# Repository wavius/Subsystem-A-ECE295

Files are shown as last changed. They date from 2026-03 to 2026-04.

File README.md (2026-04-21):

# Subsystem A
## Overview
My team was tasked with implementing Subsystem A as part of the ECE295 hardware design course. This subsystem consists of an RX Filter and Quadrature Mixer and is part of the receive chain of the Flexible Radio Transceiver (FLRTRX).

<div align="left">
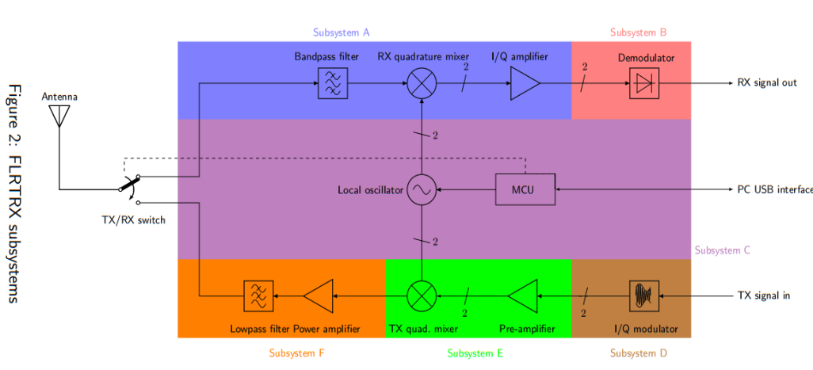
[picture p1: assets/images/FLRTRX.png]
  
</div>
<br>

## Motivation

The LNA and mixer are discrete implementations using NPN BJTs because I thought it was more fun and interesting to do it this way. I am pleased with the results and I have become much more comfortable designing and working with transistors.

I was previously quick to rush to the PCB design stage, but now have a lot more appreciation for simulation using spice. I think it is much more important (maybe obviously) to get the functionality right before arranging and routing components, even if the second part can seem more fun and less frustrating.

I had a wonderful experience with the design aspect of the course and would highly recommend others to take a similar discrete design approach.

## Design

<div align="left">
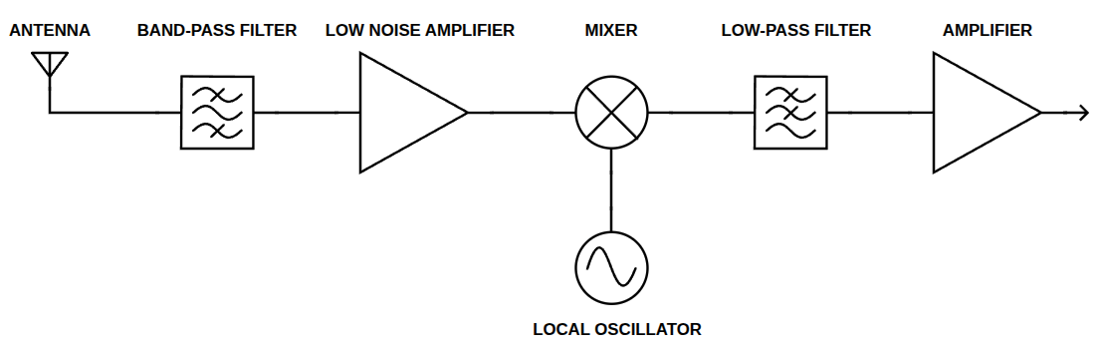
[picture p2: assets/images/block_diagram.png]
  
</div>
<br>

The design consists of five main stages that are described below in more detail.

[📄 View Schematic (PDF)](assets/pdf/Schematic.pdf)

### Band-pass Filter
* **Requirements**: 8 and 16 MHz cutoff frequencies; amplitude balance within 1dB.
* **Implementation**: 3rd-order passive Butterworth filter. 
* **Rationale**: A Butterworth response was chosen for its maximally flat passband to maintain amplitude balance across the 8-16 MHz window. A passive topology was used as the MHz-range bandwidth made active op-amp designs unfeasible.

### Low Noise Amplifier (LNA)
* **Requirements**: 50 $\Omega$ input impedance; Noise $< 3\text{nV}/\sqrt{\text{Hz}}$.
* **Implementation**: Cascode (common-emitter to common-base) amplifier.
* **Rationale**: Designed to compensate for band-pass filter insertion loss, mask noise contributions from subsequent stages, and present a 50 $\Omega$ match to the BPF to preserve the receiver signal integrity.

### Gilbert Cell Mixer
* **Requirements**: 90° (12.5° tolerance) phase difference between I/Q signals.
* **Implementation**: Active Gilbert Cell mixer.
* **Rationale**: An active topology avoids passive losses and provides superior local-oscillator-to-intermediate-frequency isolation for a cleaner output. 

### Low-pass Filter
* **Requirements**: 92 kHz cutoff frequency.
* **Implementation**: Second-order Sallen-Key active filter.
* **Rationale**: Yields a Butterworth response similar to the BPF but without passive insertion losses.

### Amplifier
* **Requirements**: $\ge 30\text{ dB}$ post-mixer gain.
* **Implementation**: Non-inverting amplifier.
* **Rationale**: Provides a dedicated stage for final gain control by swapping a single resistor while keeping previous stages isolated.

## PCB Assembly & Rework
The design was assembled using SMD components.

<div align="left">
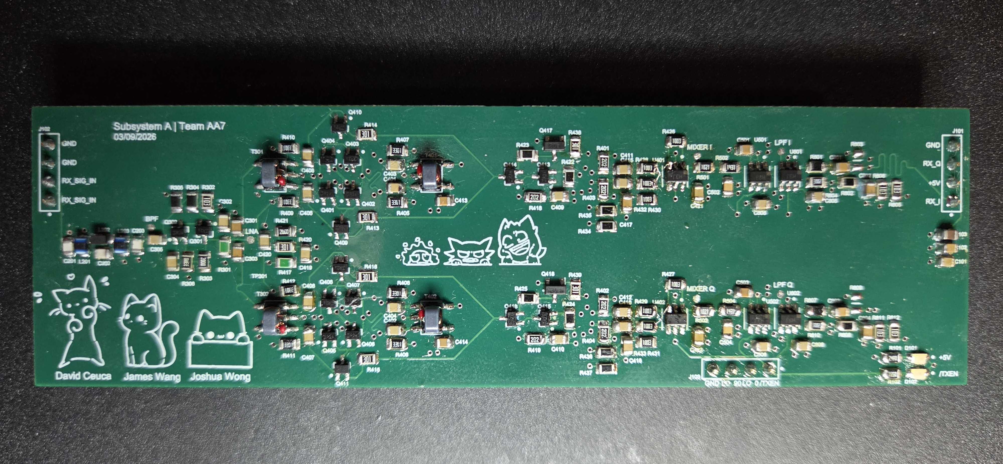
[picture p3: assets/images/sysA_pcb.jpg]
  
</div>
<br>

### Hardware Issues
During testing, it was discovered that the differential amplifier inverting and non-inverting pins were flipped during schematic capture and that this mistake made it into the final PCB. 

*Note: this issue has already been fixed in design files in this repository.*

* **Fix**: The affected op-amp pins were lifted to prevent pad contact and fine strands from a 22AWG wire were used to manually jump the pins to the correct resistor nodes.

<br>
<div align="left">
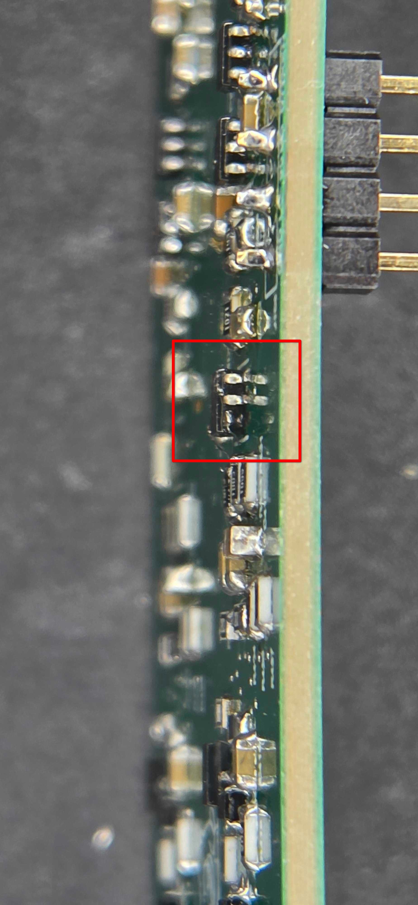
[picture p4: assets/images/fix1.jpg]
Fix 1
  
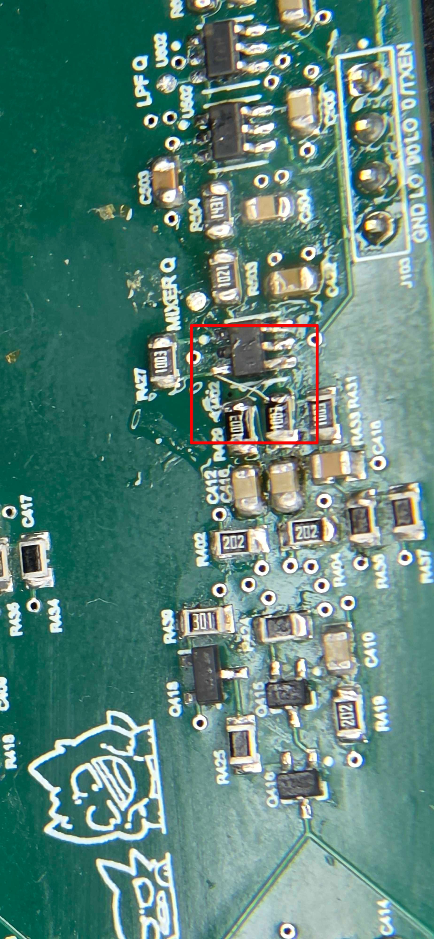
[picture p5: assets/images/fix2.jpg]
Fix 2
  
</div>
<br>

## Testing & Results

To verify the design, a $12.05\text{ MHz}$ RF signal was mixed with $12\text{ MHz}$ LO signals. The output signals were measured to be the correct $50\text{ kHz}$ intermediate frequency (IF), with the I and Q channels $90^\circ$ out of phase.

<div align="left">
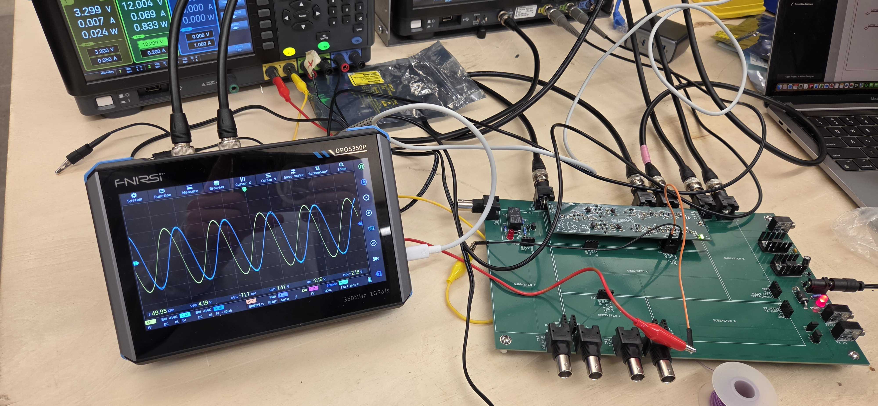
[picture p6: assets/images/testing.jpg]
  
</div>
<br>

Automated Python scripts were used to produce Bode plots for each stage.

| Band-pass Filter | Amplitude Balance |
| :---: | :---: |
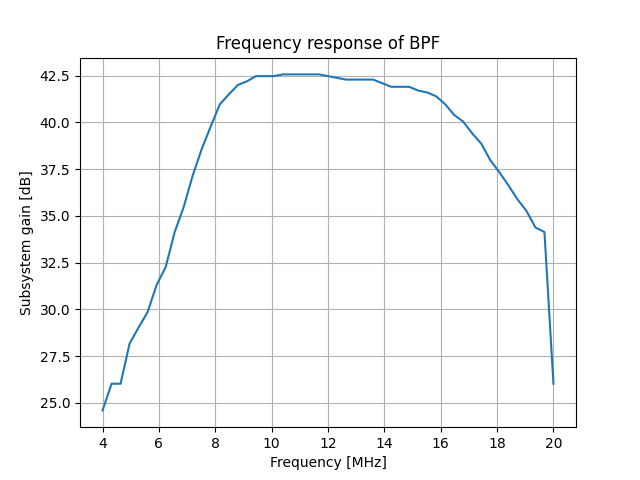
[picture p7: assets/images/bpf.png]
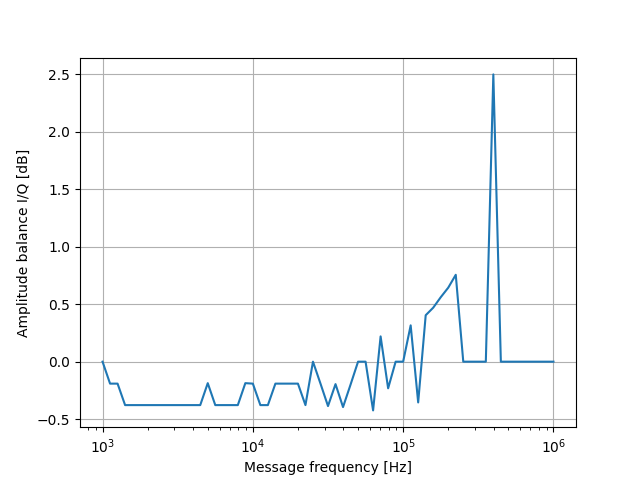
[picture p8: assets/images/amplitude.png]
|  |  |
| *Frequency response across the target passband* | *Balance difference between I/Q signals* |

| Low-pass Filter | I/Q Phase Difference |
| :---: | :---: |
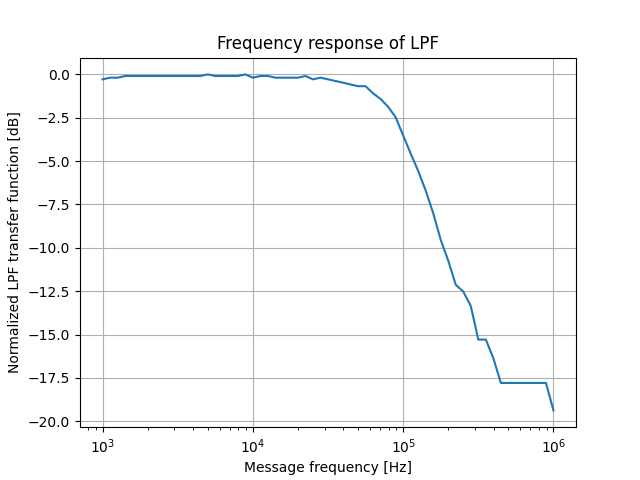
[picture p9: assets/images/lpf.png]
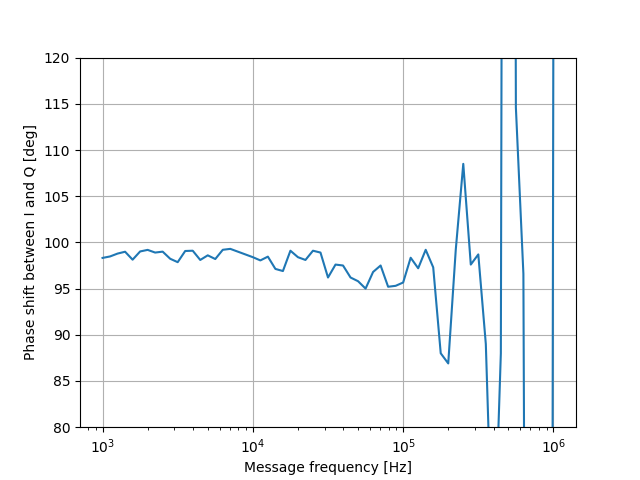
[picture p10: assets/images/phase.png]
|  |  |
| *92 kHz cutoff frequency response* | *90° quadrature separation verification* |

| Total Subsystem Gain |
| :---: |
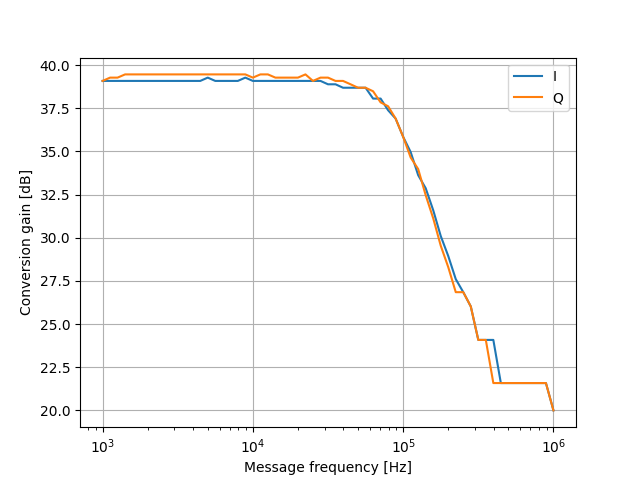
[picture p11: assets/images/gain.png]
|  |
| *Total signal gain throughout all stages* |

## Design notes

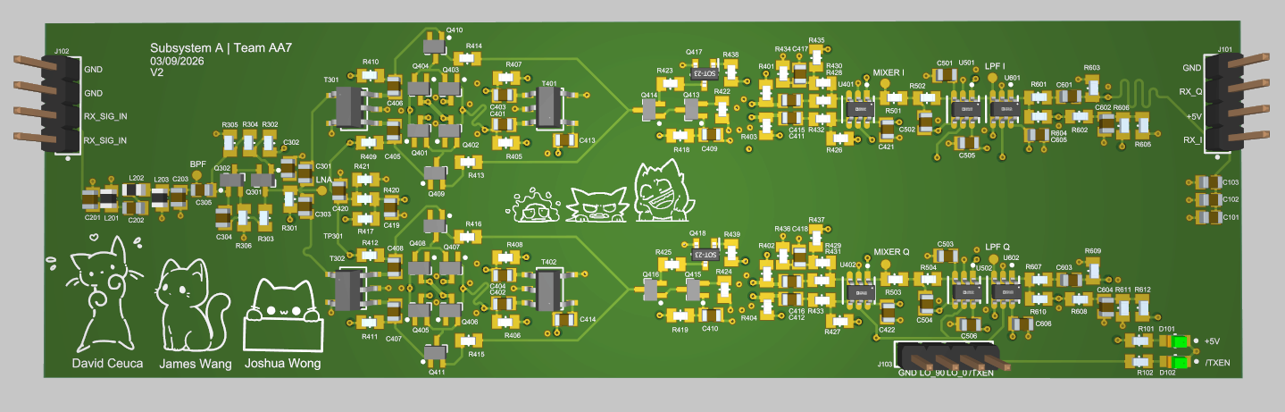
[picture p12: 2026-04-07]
assets/images/PCB_3D.png

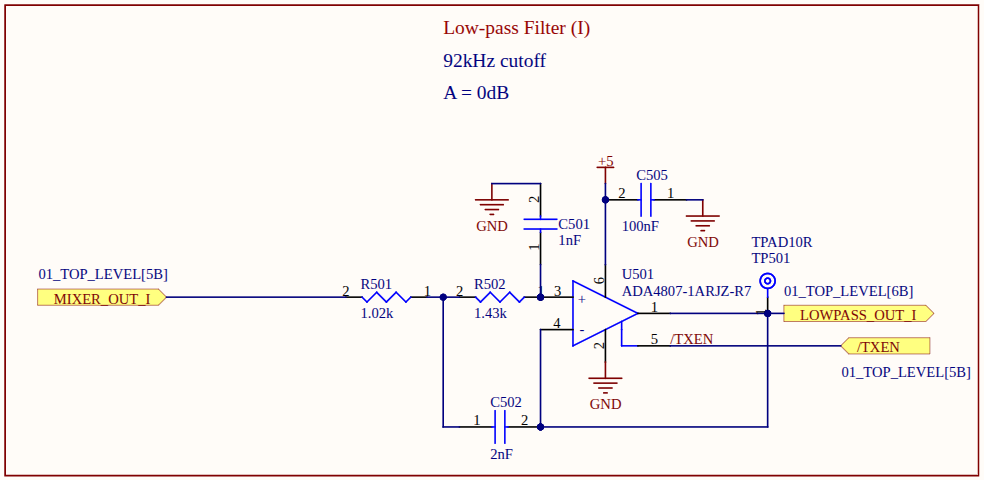
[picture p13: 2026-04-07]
assets/images/lpf_sch.png

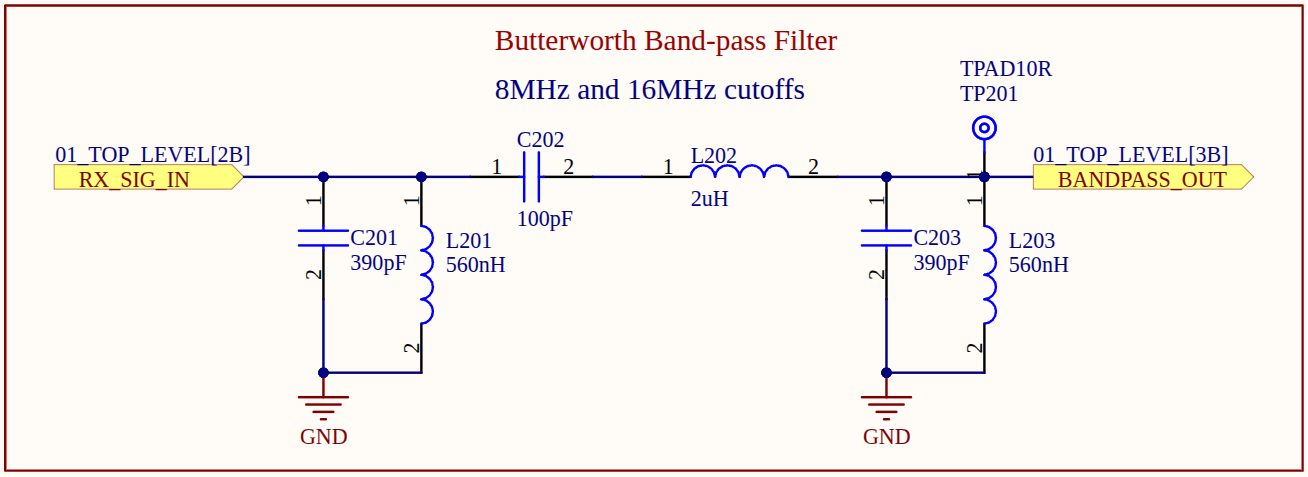
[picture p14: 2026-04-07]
assets/images/bpf_sch.png

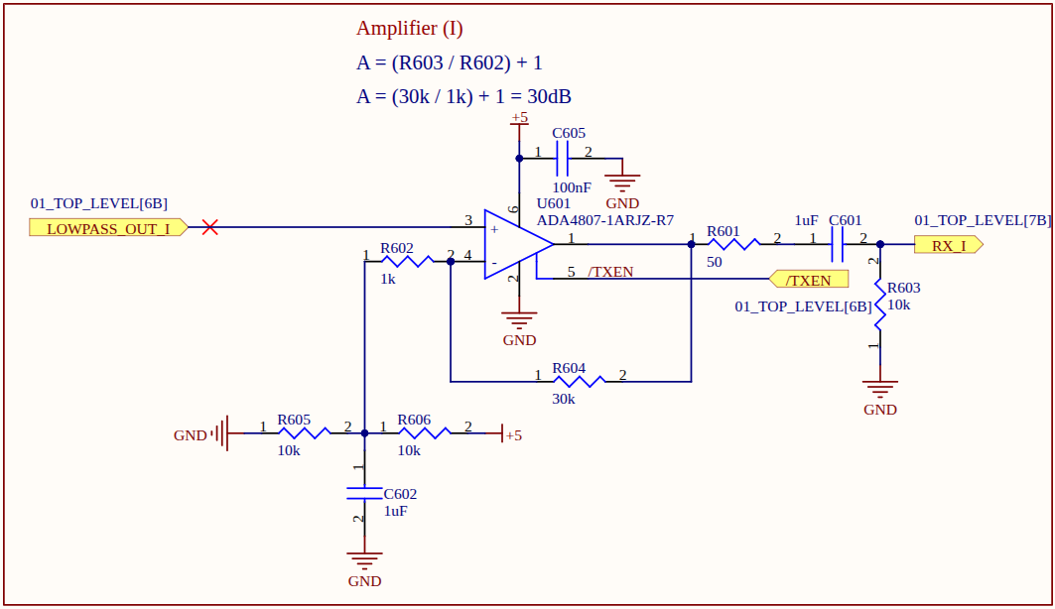
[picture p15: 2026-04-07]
assets/images/amplifier_sch.png

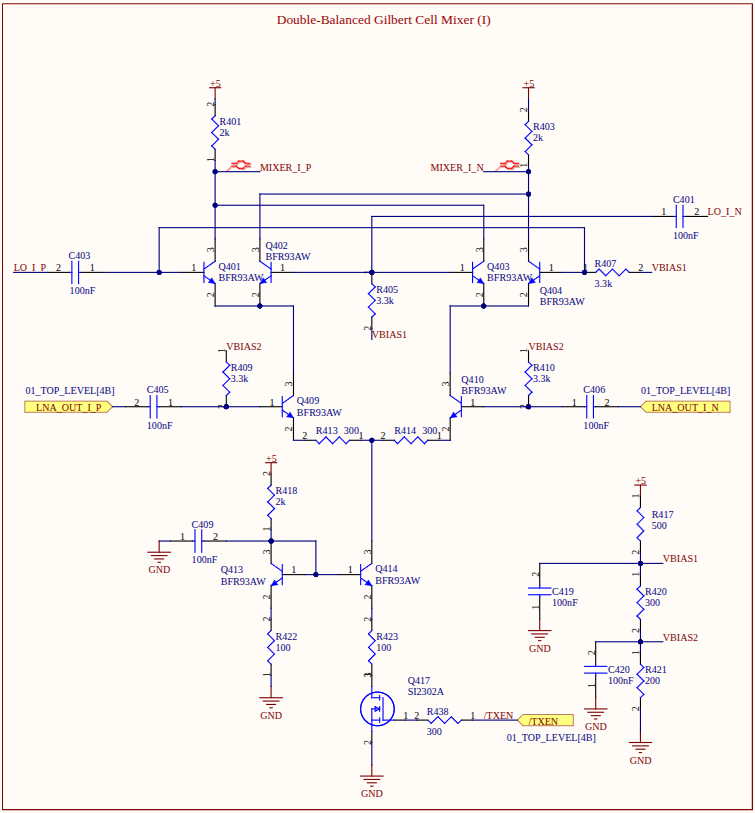
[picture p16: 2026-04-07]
assets/images/mixer_sch.png

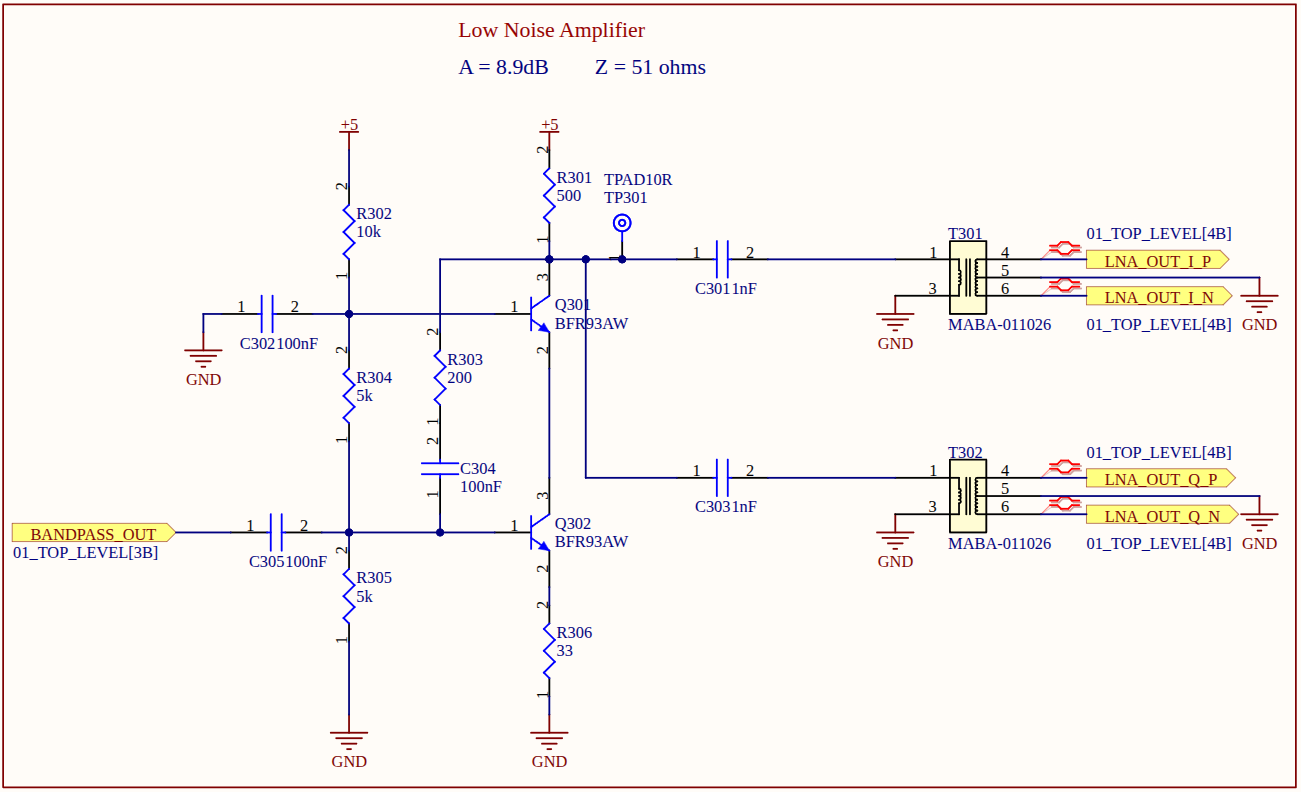
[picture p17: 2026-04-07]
assets/images/lna_sch.png

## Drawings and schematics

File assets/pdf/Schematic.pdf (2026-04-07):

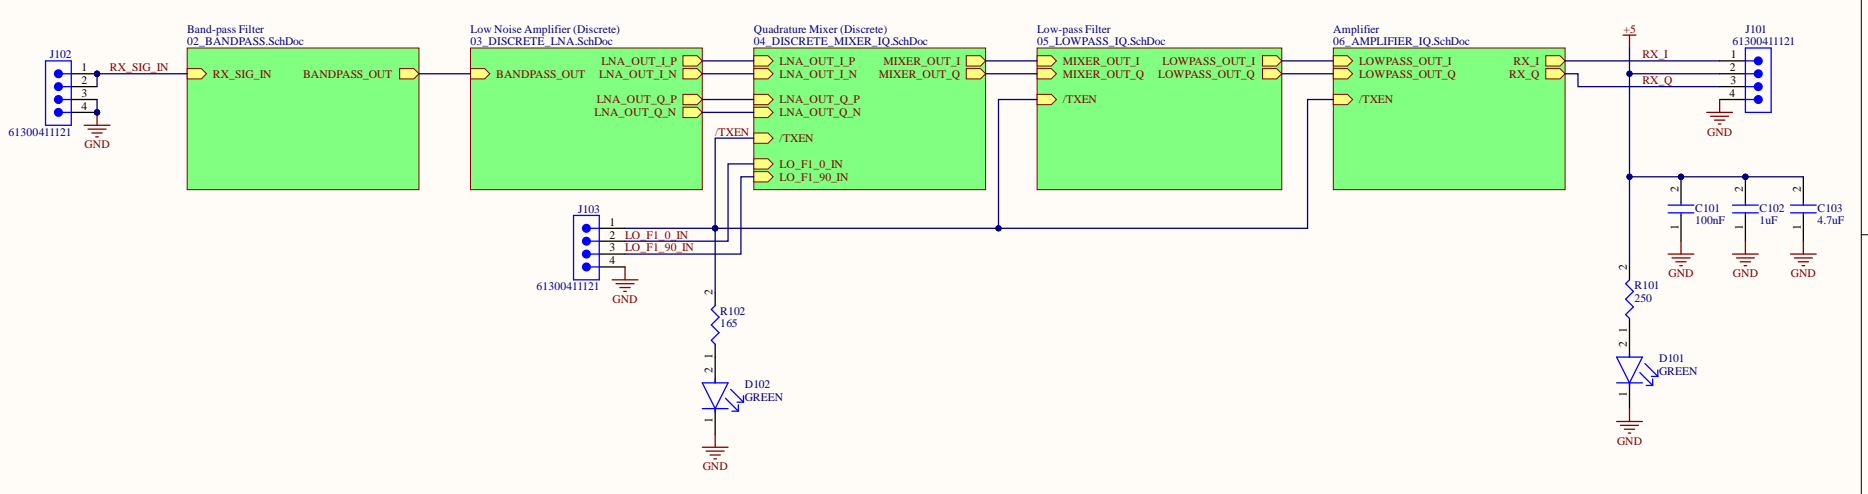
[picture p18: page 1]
ifier (D; ure Mi; xer (D

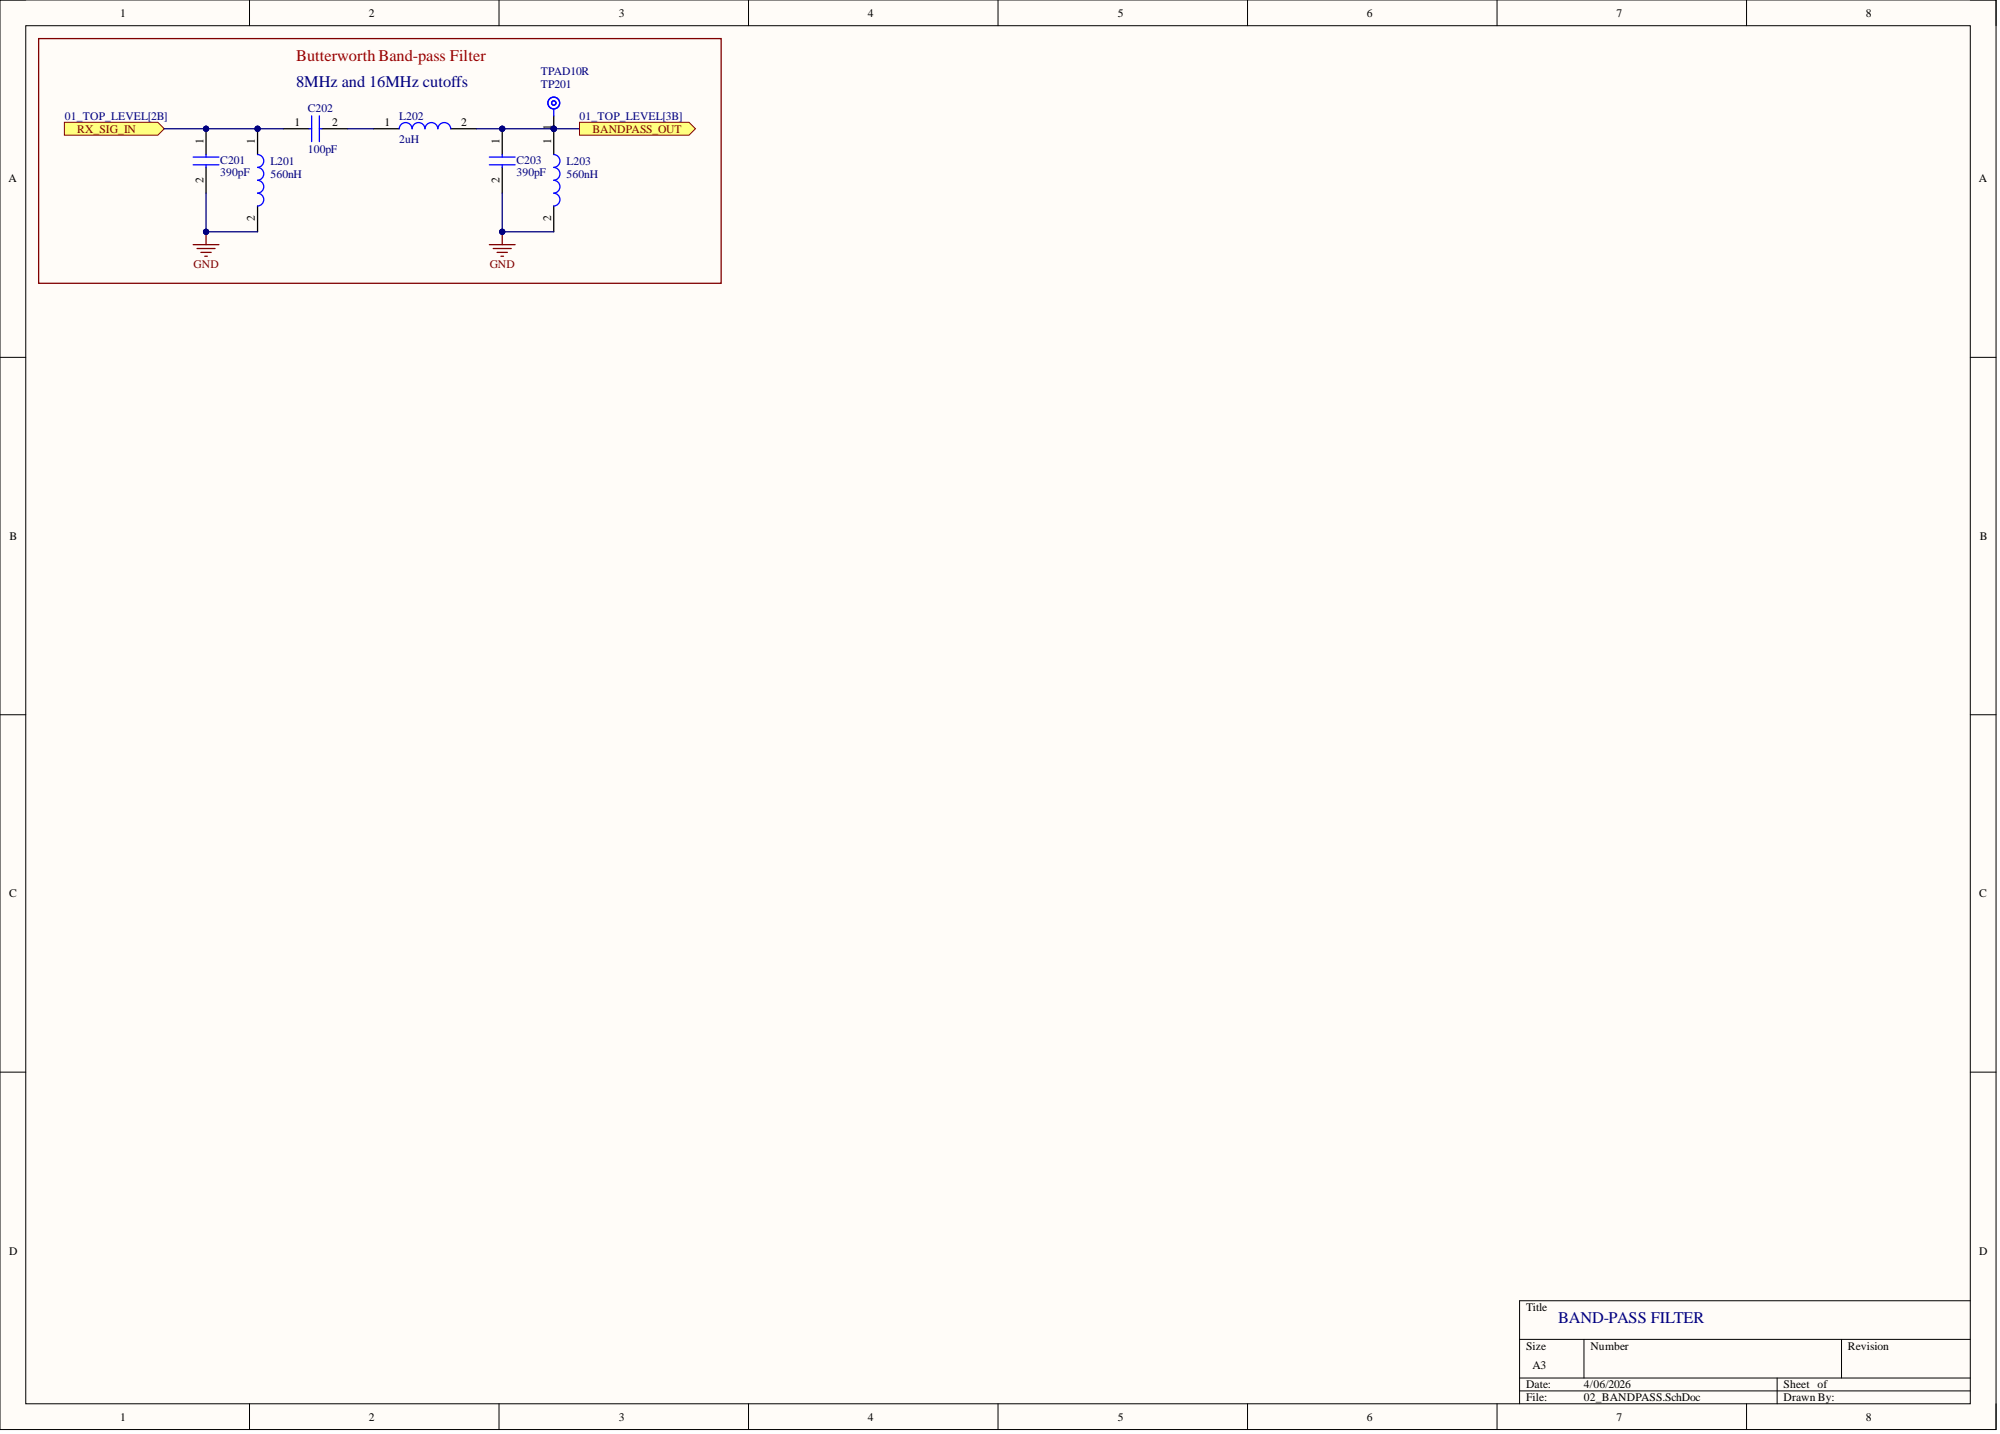
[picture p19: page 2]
Date:; Sheet of; File:; 02_BANDPASS.SchDoc; Drawn By:

Butterworth Band-pass Filter
8MHz and 16MHz cutoffs

Title
BAND-PASS FILTER

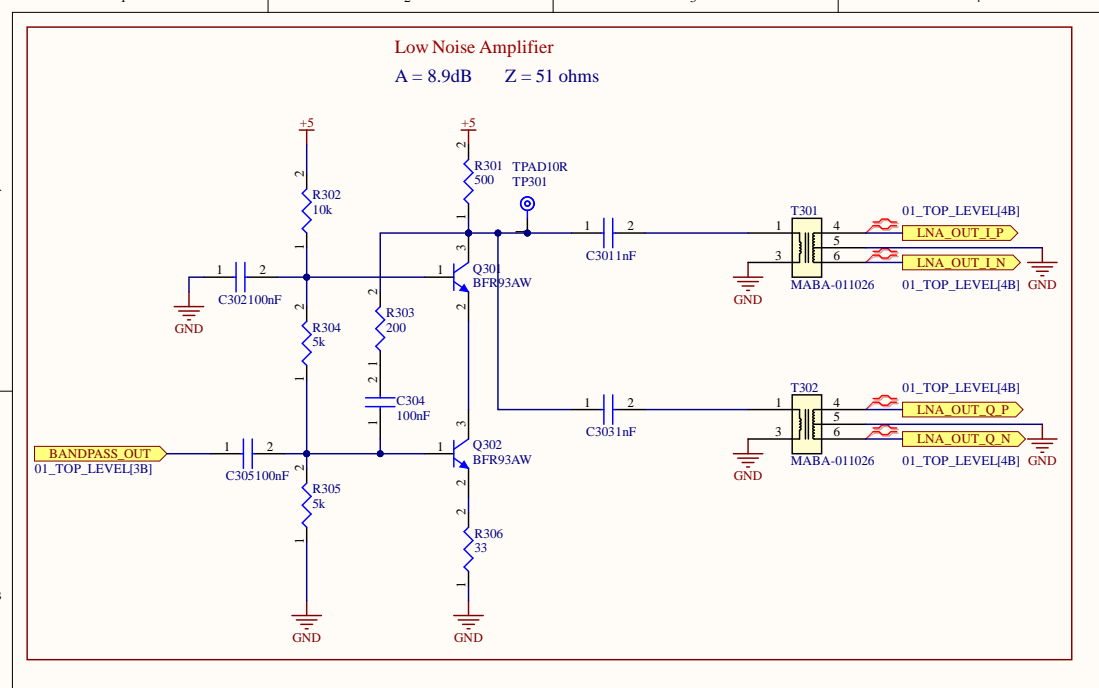
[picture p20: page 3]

Low Noise A = 8.9dB 0 2 | A mpl ifier Z = 51 ohm s

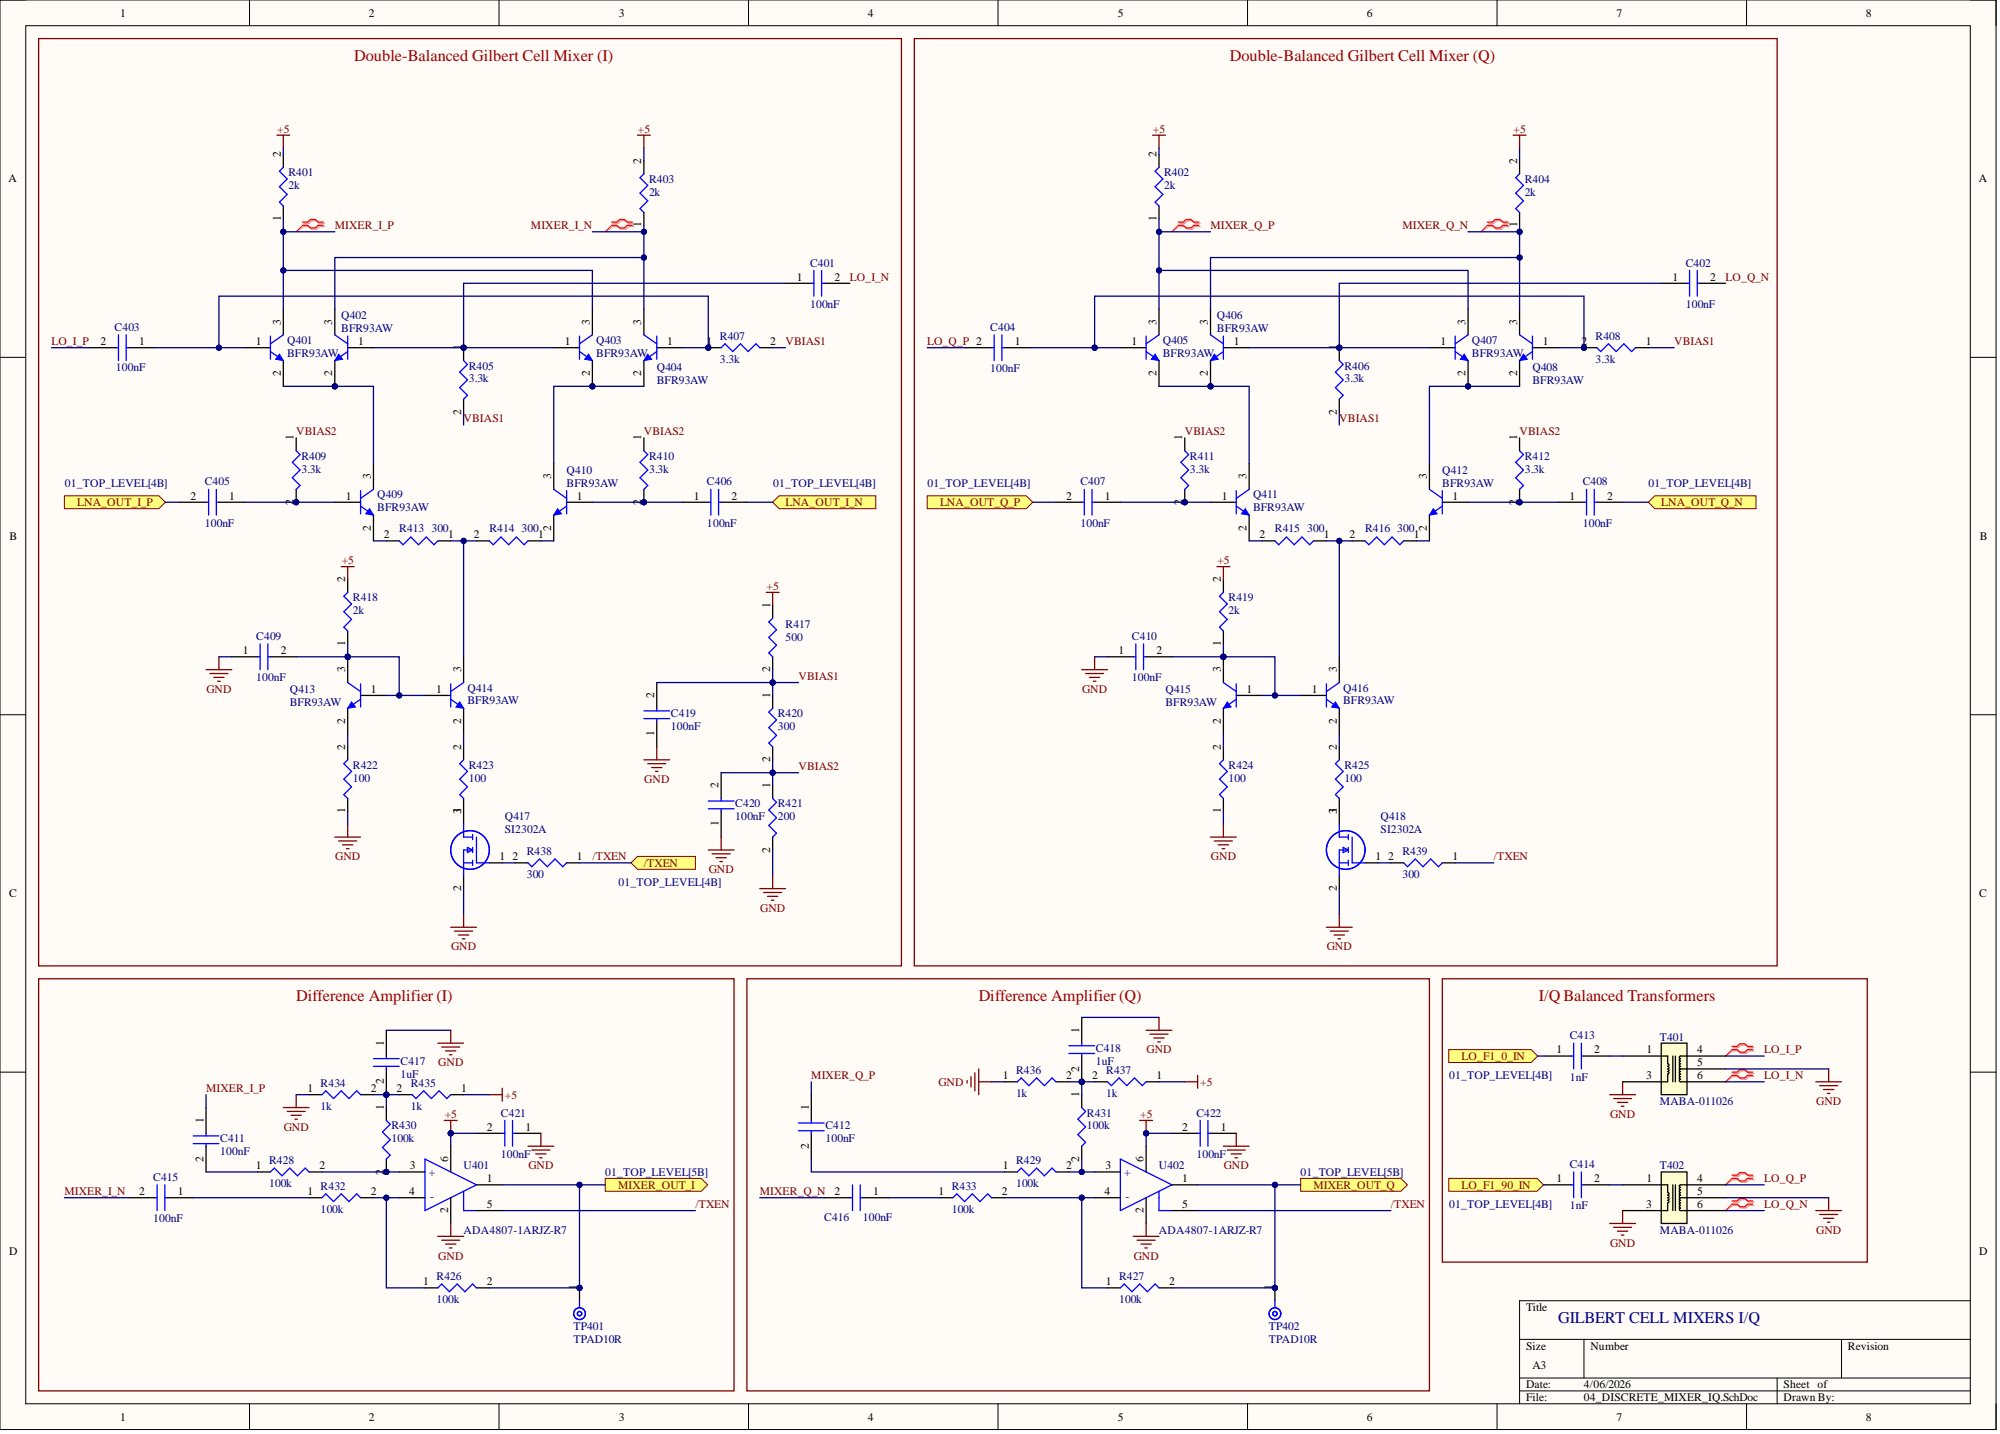
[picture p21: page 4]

Double-Balanced Gilbert Cell Mixer (I)

Double-Balanced Gilbert Cell Mixer (Q)

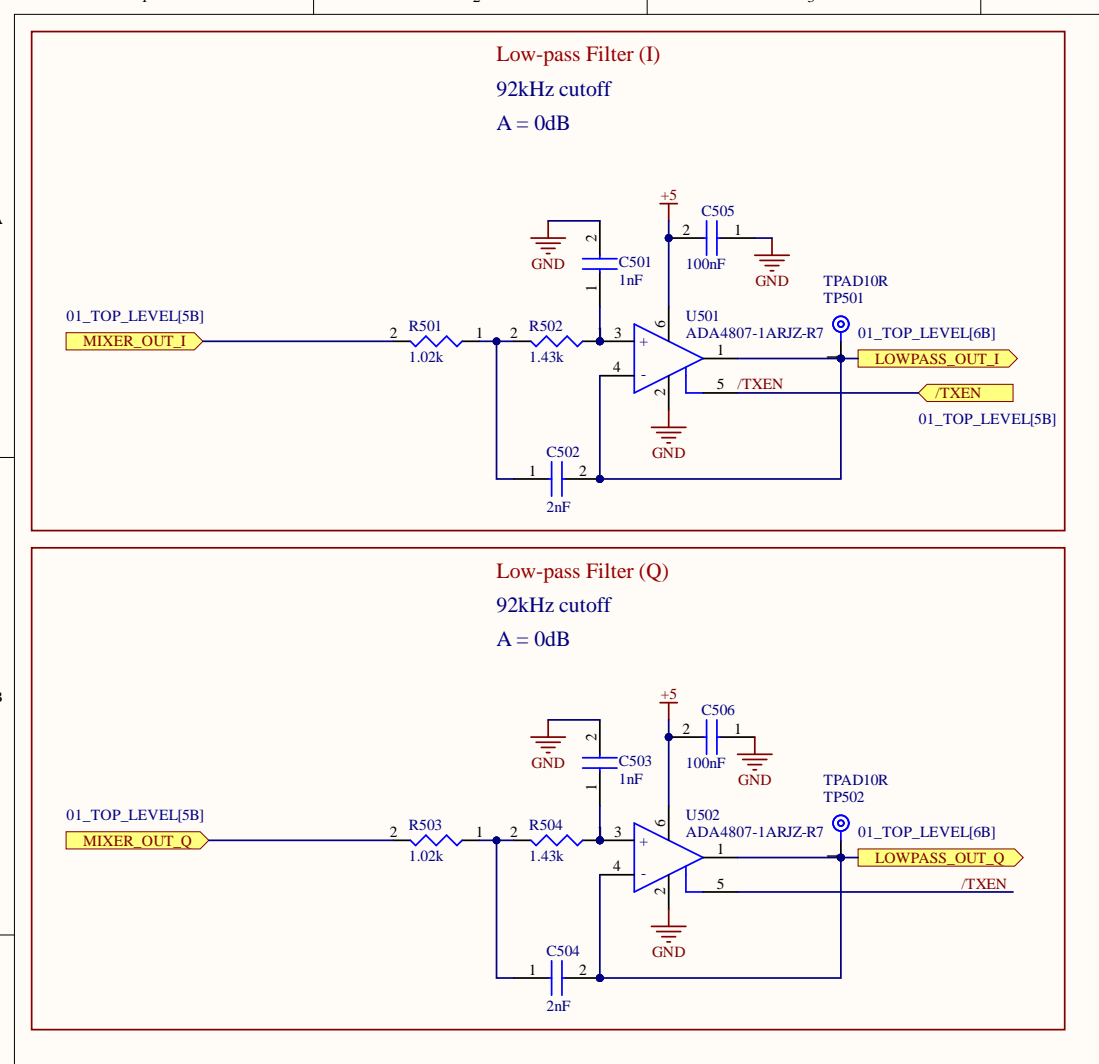
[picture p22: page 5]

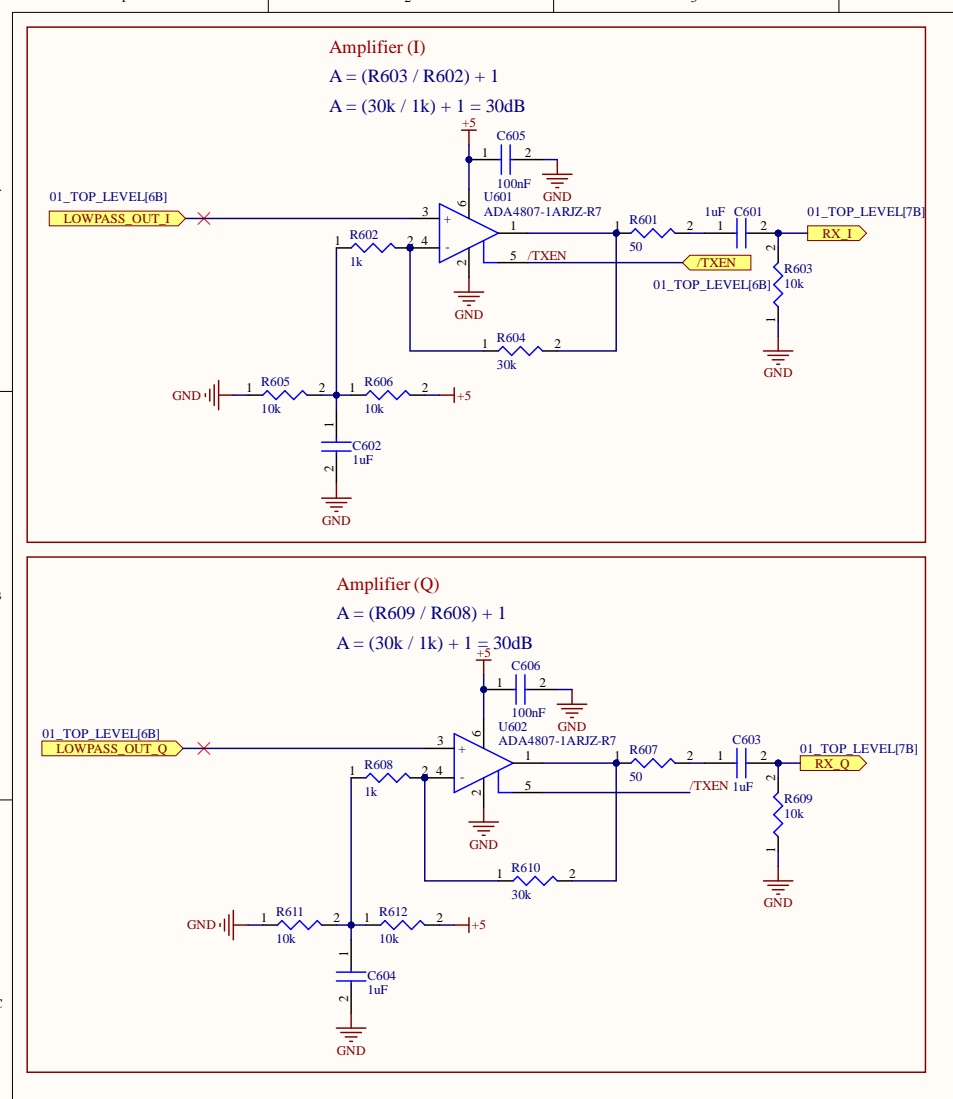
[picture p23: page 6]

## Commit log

2026-03-11 Add Altium project, update README
    [01_TOP_LEVEL.SchDoc, 02_BANDPASS.SchDoc, 03_DISCRETE_LNA.SchDoc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]
2026-04-07 update altium files, update readme
    [04_DISCRETE_MIXER_IQ.SchDoc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]
